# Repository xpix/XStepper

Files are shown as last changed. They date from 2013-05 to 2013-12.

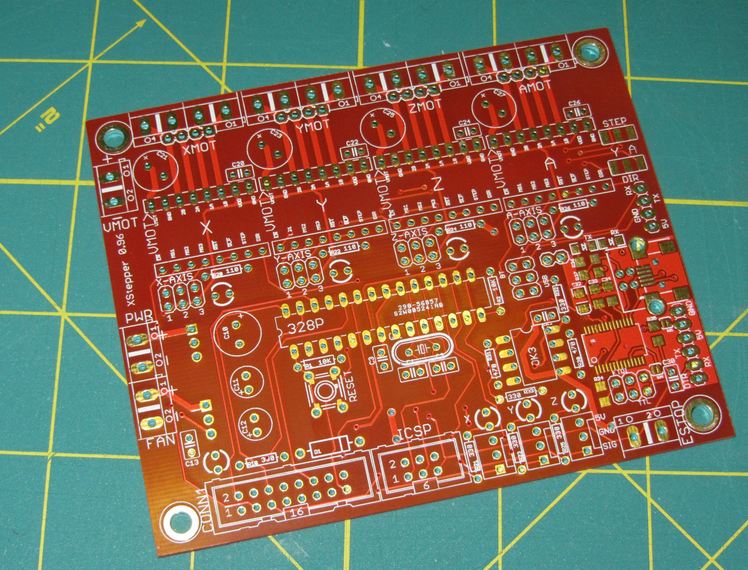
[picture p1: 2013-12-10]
Docs/board_096.JPG

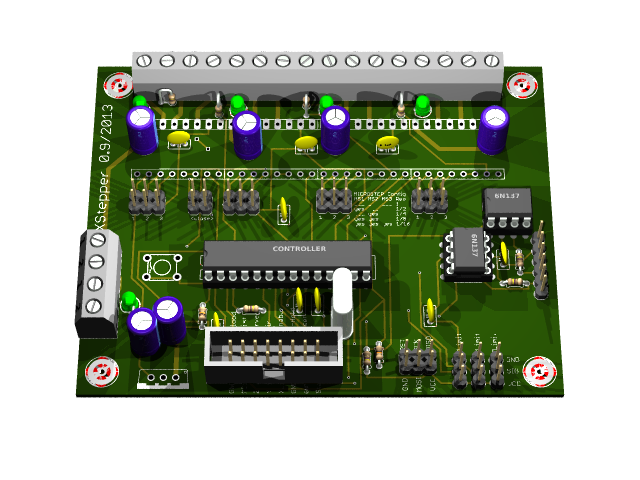
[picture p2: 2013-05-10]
eagle3d/XStepper.bmp

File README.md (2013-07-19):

XStepper
=============

A new Solution with Grbl Firmware to use cnc mills or 3d printers.

created by Frank Herrmann (xpix), Godsplan

---------------

The XStepper includes the following features:

- ATMega328u (DIL Package)
- USB Connection using USB-FTDI
- Opto-Couplers for USB Connection
- ICSP-Connector for flashing the firmware
- GRBL Firmware (v0.8) and GRBL Pinout
- Connector for External Buttons for spindle, reset, etc...
- Support for four Pololu A4988 or Pololu DRV8825 Modules
- Supports dual-Y motion
- Supports cooling fan
- Supports XYZ-Limit in extra pinheader
- LED's for every axis
- LED's for every Limit
- Power LED
- AK500 Screw terminal for Steppers
- Connector for Bluetooth TTL Modules

---------------
v0.9.1

- add optional pullup resistors (1k/5V) for Hallo Sesnor switches (Cherry MP101401)
   http://www.cherrycorp.com/english/sensors/pdf/MP1014_Series.pdf

v0.9 

- created schema files
- created .brd

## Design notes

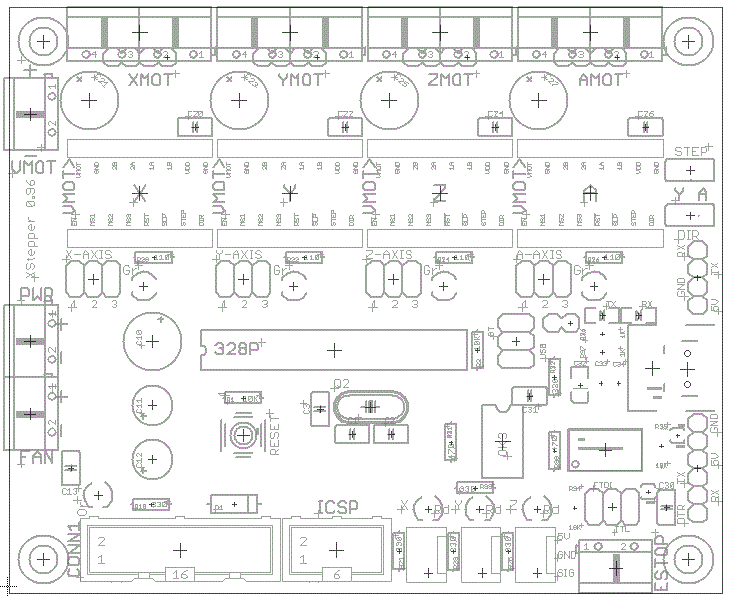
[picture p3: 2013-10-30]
Docs/board_top.gif

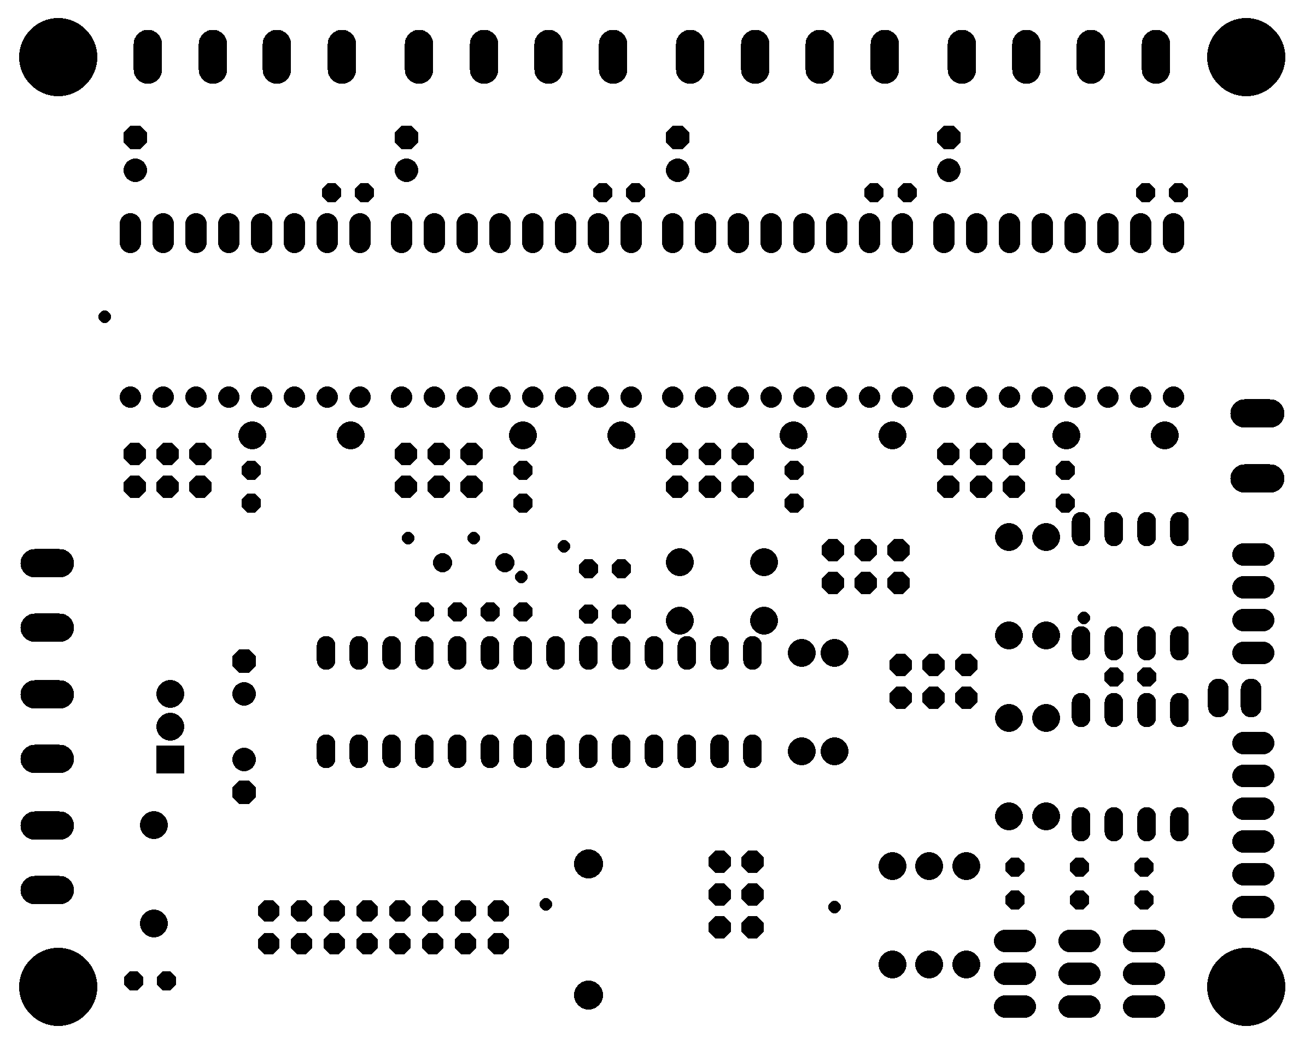
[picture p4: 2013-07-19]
eagleUp/eagleUp_XStepper_bottom_mask.png

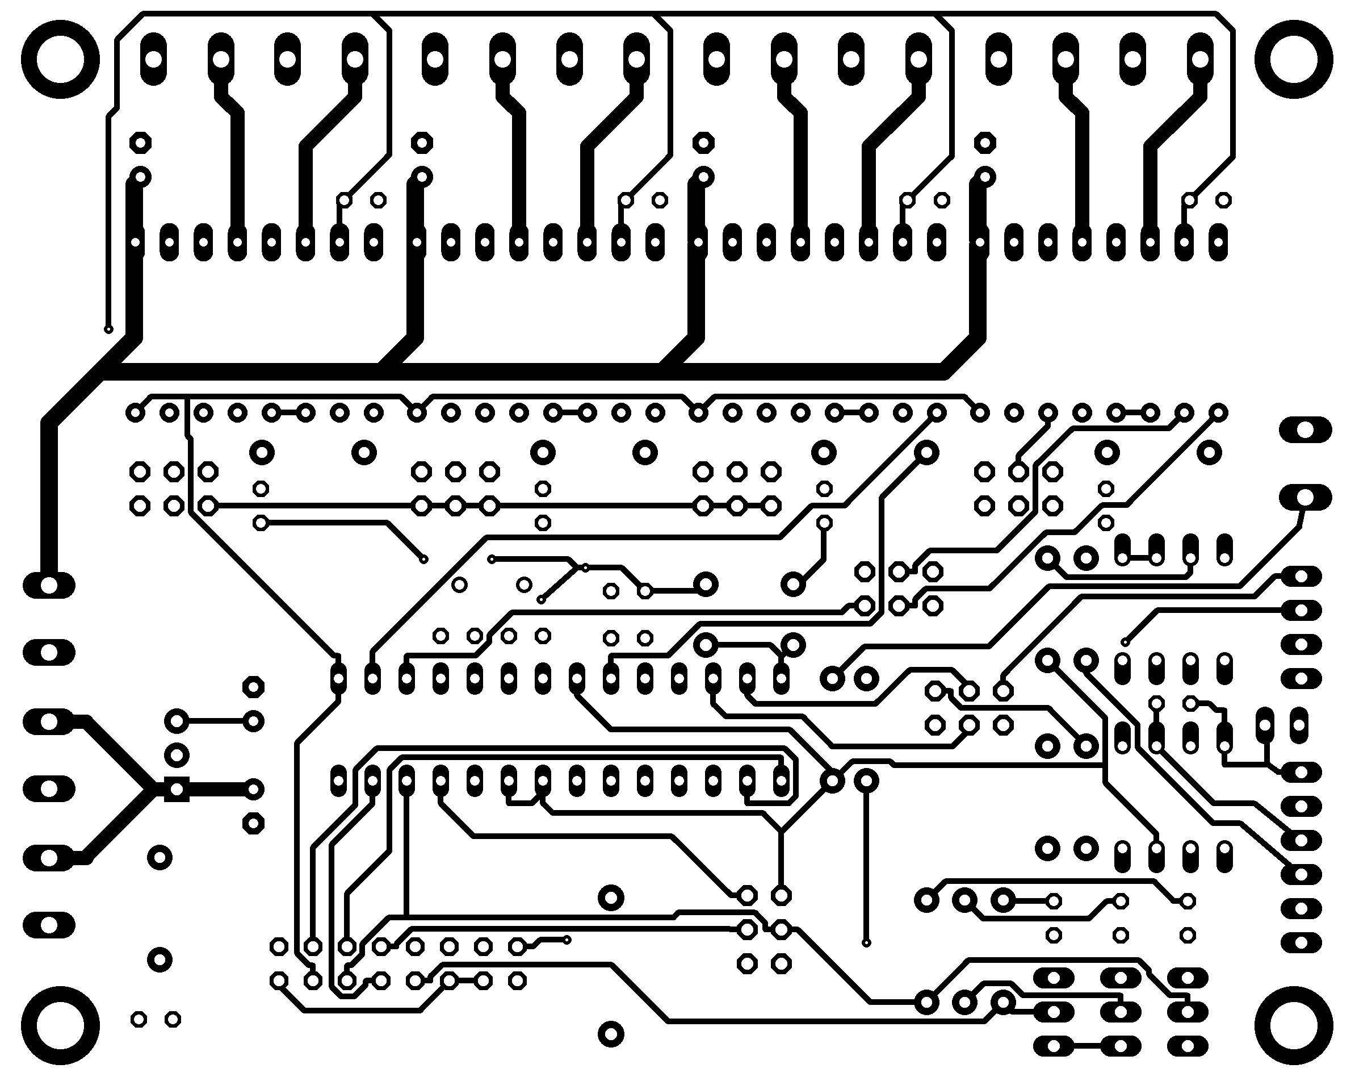
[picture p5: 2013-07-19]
eagleUp/eagleUp_XStepper_top.png

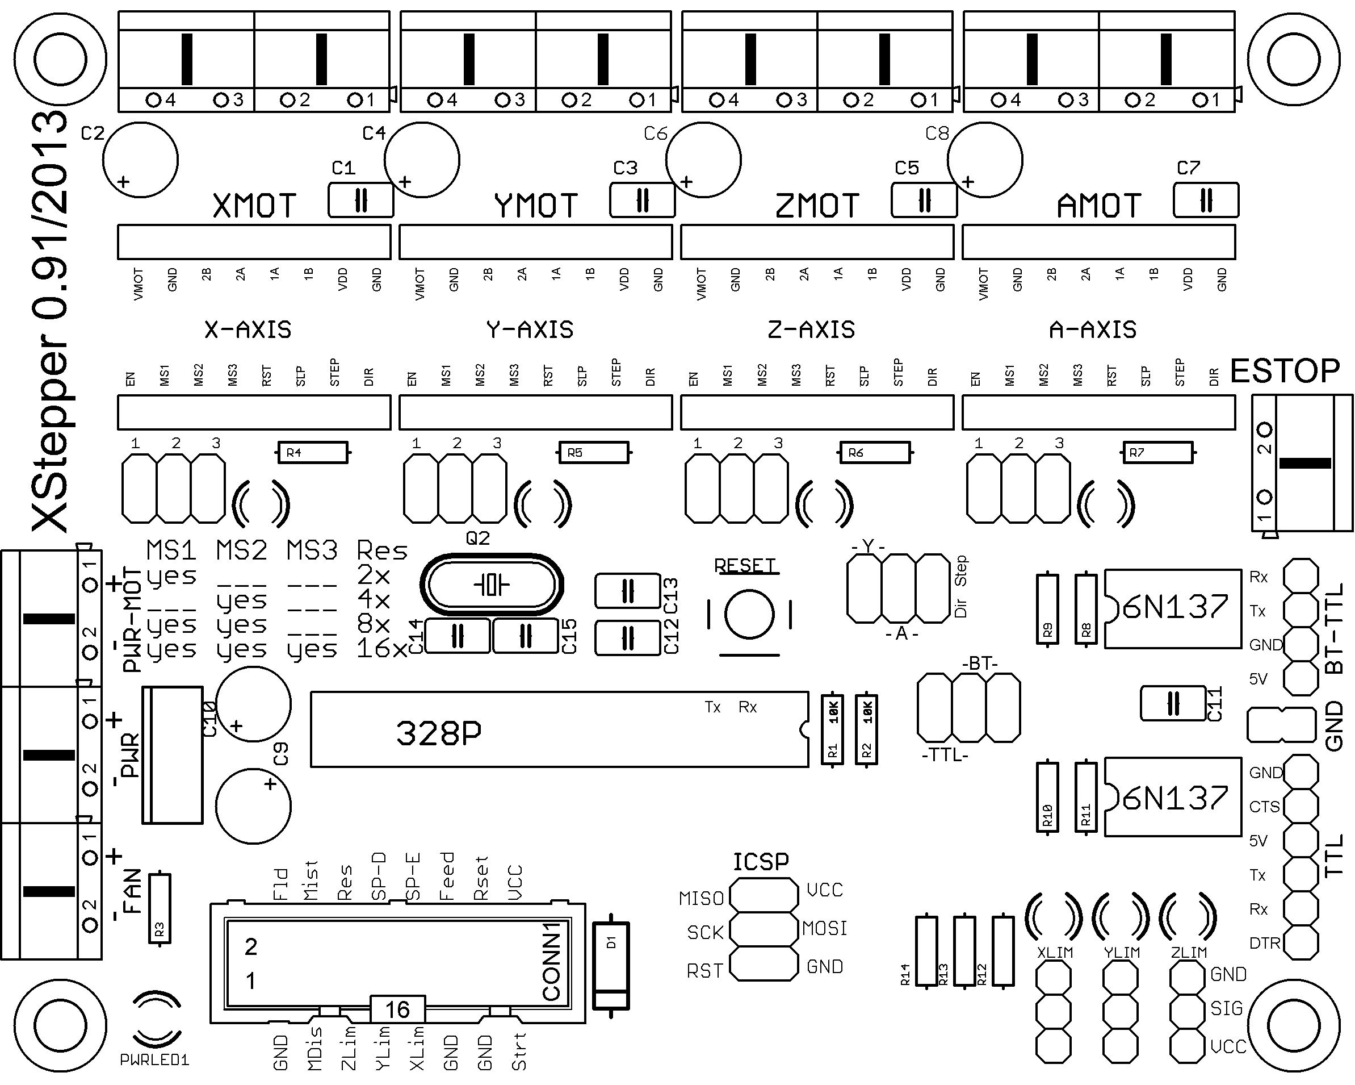
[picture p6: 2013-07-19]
eagleUp/eagleUp_XStepper_top_silk.png

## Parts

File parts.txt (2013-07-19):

Partlist

Exported from XStepper.sch at 11.07.2013 17:57:24

EAGLE Version 6.3.0 Copyright (c) 1988-2012 CadSoft

Assembly variant: 

Part           Value              Device             Package            Library        Sheet

328P           CONTROLLER         MEGA8-P            DIL28-3            Bibsatmel      1
A-AXIS                            PINHD-2X3          2X03               pinhead        1
ALED                              LED3MM             LED3MM             led            1
AMOT                              AK500/4            AK500/4            con-ptr500     1
BT-TTL                            PINHD-1X4          1X04               pinhead        1
C1             0.1uF              C-EU025-025X050    C025-025X050       resistor       1
C2             47uF               CPOL-USE2.5-6      E2,5-6             resistor       1
C3             0.1uF              C-EU025-025X050    C025-025X050       resistor       1
C4             0.1uF              C-EU025-025X050    C025-025X050       resistor       1
C5             47uF               CPOL-USE2.5-6      E2,5-6             resistor       1
C6             0.1uF              C-EU025-025X050    C025-025X050       resistor       1
C7             47uF               CPOL-USE2.5-6      E2,5-6             resistor       1
C8             47uF               CPOL-USE2.5-6      E2,5-6             resistor       1
C9             47uF               CPOL-USE2.5-6      E2,5-6             resistor       1
C10            47uF               CPOL-USE2.5-6      E2,5-6             resistor       1
C11            18pF               C-EU025-025X050    C025-025X050       resistor       1
C12            18pF               C-EU025-025X050    C025-025X050       resistor       1
C13            0.1uF              C-EU025-025X050    C025-025X050       resistor       1
C14            0.1uF              C-EU025-025X050    C025-025X050       resistor       1
C15            0.1uF              C-EU025-025X050    C025-025X050       resistor       1
CONN1                             ML16               ML16               con-ml         1
DUALY                             PINHD-2X2          2X02               pinhead        1
FAN                               AK500/2            AK500/2            con-ptr500     1
H5             MOUNT-PAD-ROUND3.6 MOUNT-PAD-ROUND3.6 3,6-PAD            holes          1
H6             MOUNT-PAD-ROUND3.6 MOUNT-PAD-ROUND3.6 3,6-PAD            holes          1
H7             MOUNT-PAD-ROUND3.6 MOUNT-PAD-ROUND3.6 3,6-PAD            holes          1
H8             MOUNT-PAD-ROUND3.6 MOUNT-PAD-ROUND3.6 3,6-PAD            holes          1
IC1             LM7805            V_REG_78XX         78XXL-CUSTOM       SparkFun       1
ICSP                              PINHD-2X3          2X03               pinhead        1
OK1            6N137              6N137              DIL08              optocoupler    1
OK2            6N137              6N137              DIL08              optocoupler    1
PWR                               AK500/2            AK500/2            con-ptr500     1
PWRLED1                           LED3MM             LED3MM             led            1
Q2             16 MHZ             CRYSTALHC49S       HC49/S             crystal        1
R1             10k                R-EU_0204/5        0204/5             resistor       1
R2             470                R-EU_0204/5        0204/5             resistor       1
R3             470                R-EU_0204/5        0204/5             resistor       1
R4             470                R-EU_0204/5        0204/5             resistor       1
R5             470                R-EU_0204/2V       0204V              resistor       1
R6             10k                R-EU_0204/5        0204/5             resistor       1
R7             470                R-EU_0204/5        0204/5             resistor       1
R8             470                R-EU_0204/2V       0204V              resistor       1
R9             470                R-EU_0204/2V       0204V              resistor       1
R10            470                R-EU_0204/2V       0204V              resistor       1
R11            470                R-EU_0204/2V       0204V              resistor       1
R12            470                R-EU_0204/2V       0204V              resistor       1
R13            1k                 R-EU_0204/2V       0204V              resistor       1
R14            470                R-EU_0204/2V       0204V              resistor       1
R15            1k                 R-EU_0204/2V       0204V              resistor       1
R16            1k                 R-EU_0204/2V       0204V              resistor       1
R17            1k                 R-EU_0204/2V       0204V              resistor       1
RESET          RESET              TAC_SWITCHPTH      TACTILE-PTH        SparkFun       1
STEPPERDRIVER  POLOLU-A4988       POLOLU-ALLEGRO     POLOLU-ALLEGRO-PTH pololu-allegro 1
STEPPERDRIVER1 POLOLU-A4988       POLOLU-ALLEGRO     POLOLU-ALLEGRO-PTH pololu-allegro 1
STEPPERDRIVER2 POLOLU-A4988       POLOLU-ALLEGRO     POLOLU-ALLEGRO-PTH pololu-allegro 1
STEPPERDRIVER3 POLOLU-A4988       POLOLU-ALLEGRO     POLOLU-ALLEGRO-PTH pololu-allegro 1
TTL            GND                PINHD-1X6          1X06               pinhead        1
X-AXIS                            PINHD-2X3          2X03               pinhead        1
XLED                              LED3MM             LED3MM             led            1
XLIMIT                            PINHD-1X3          1X03               pinhead        1
XMOT                              AK500/4            AK500/4            con-ptr500     1
XSTLED                            LED3MM             LED3MM             led            1
Y-AXIS                            PINHD-2X3          2X03               pinhead        1
YLED                              LED3MM             LED3MM             led            1
YLIMIT                            PINHD-1X3          1X03               pinhead        1
YMOT                              AK500/4            AK500/4            con-ptr500     1
YSTLED                            LED3MM             LED3MM             led            1
Z-AXIS                            PINHD-2X3          2X03               pinhead        1
ZLED                              LED3MM             LED3MM             led            1
ZLIMIT                            PINHD-1X3          1X03               pinhead        1
ZMOT                              AK500/4            AK500/4            con-ptr500     1
ZSTLED                            LED3MM             LED3MM             led            1

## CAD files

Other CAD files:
eagleUp/XStepper.skp

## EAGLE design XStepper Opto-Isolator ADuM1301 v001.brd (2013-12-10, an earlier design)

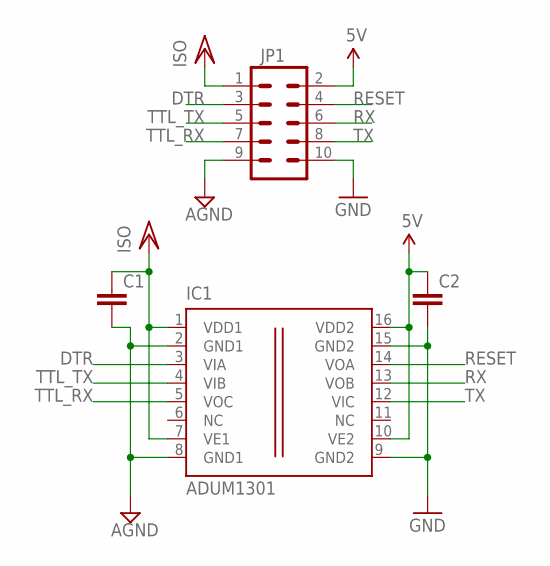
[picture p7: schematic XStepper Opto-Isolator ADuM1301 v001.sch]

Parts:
C1, C2: CAP0805; 0805
IC1: ADUM1301; SO-16W
JP1: M05X2PTH; AVR_ICSP

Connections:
5V: C2.1, IC1.10 (VE2), IC1.16 (VDD2), JP1.2
AGND: C1.2, IC1.2 (GND1), IC1.8 (GND1), JP1.9
DTR: IC1.3 (VIA), JP1.3
GND: C2.2, IC1.9 (GND2), IC1.15 (GND2), JP1.10
RESET: IC1.14 (VOA), JP1.4
RX: IC1.13 (VOB), JP1.6
TTL_RX: IC1.5 (VOC), JP1.7
TTL_TX: IC1.4 (VIB), JP1.5
TX: IC1.12 (VIC), JP1.8
VCC/2: C1.1, IC1.1 (VDD1), IC1.7 (VE1), JP1.1

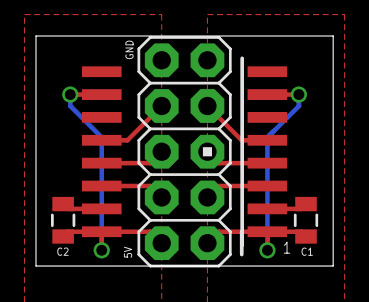
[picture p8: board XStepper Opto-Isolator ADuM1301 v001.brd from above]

Board: 2 copper layers, 16.5 x 12.8 mm, 4 parts (0 on the bottom side), 10 nets.

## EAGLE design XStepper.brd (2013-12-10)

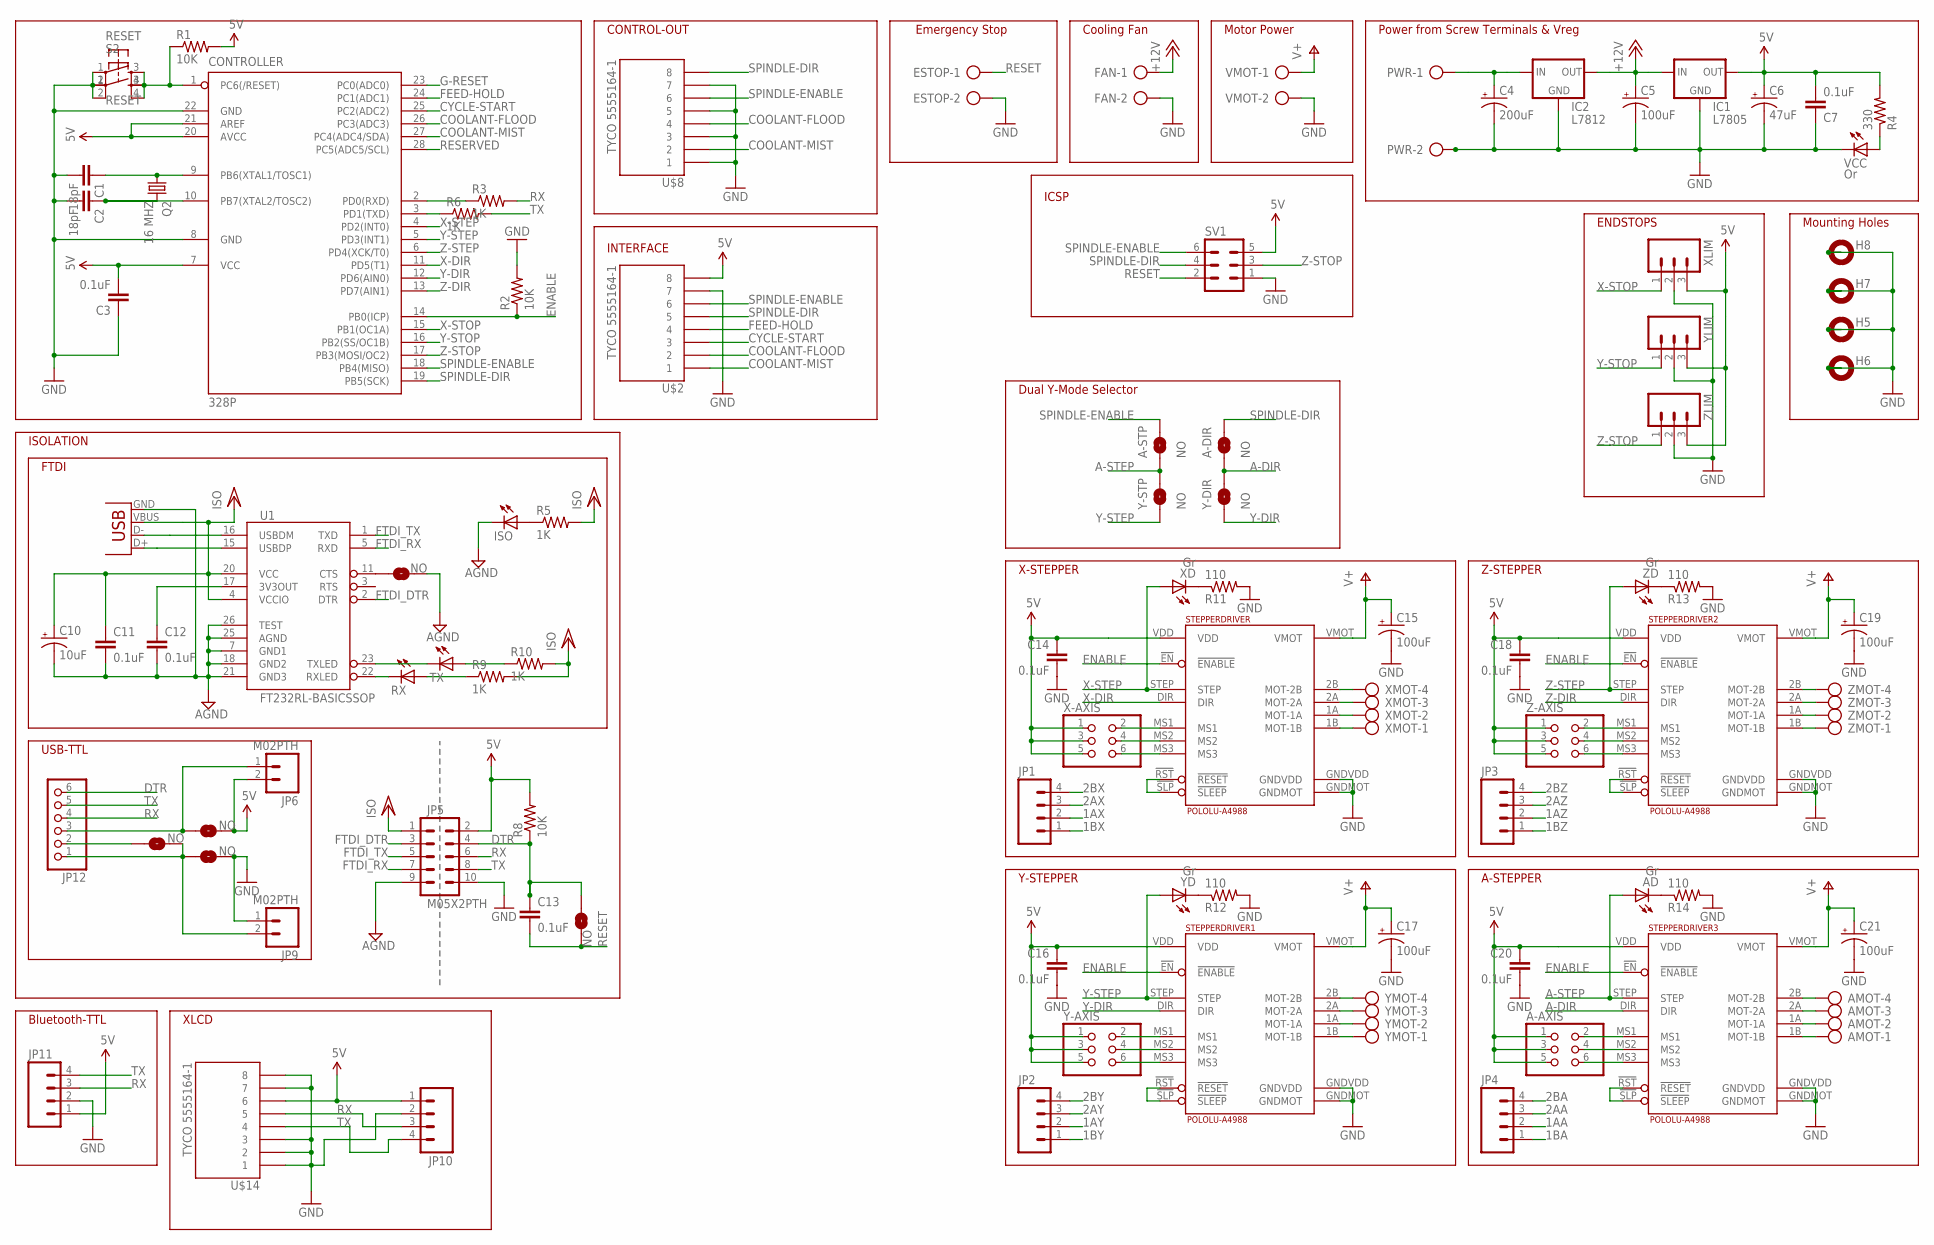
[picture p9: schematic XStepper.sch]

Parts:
5V: NO; SJ_2S-NO
328P: CONTROLLER; DIL28-3
A-AXIS: PINHD-2X3; 2X03
A-DIR: NO; SJ_2S-NO
A-STP: NO; SJ_2S-NO
AD: Gr; LED3MM
AMOT: AK500/4
C1, C2: 18pF; C025-025X050
C3, C7, C13, C14, C16, C18, C20: 0.1uF; C025-025X050
C4: 200uF; E3,5-8
C5: 100uF; E2,5-6
C6: 47uF; E2,5-6
C10: 10uF; EIA3216
C11, C12: 0.1uF; 1206
C15, C17, C19, C21: 100uF; E3,5-8
CTS: NO; SJ_2S-NO
CTS-FTDI: NO; SJ_2S-NO
DTR: NO; SJ_2S-NO
ESTOP: AK500/2
FAN: AK500/2
GND: NO; SJ_2S-NO
H5, H6, H7, H8: MOUNT-PAD-ROUND3.6; 3,6-PAD
IC1: L7805; TO220-IGO
IC2: L7812; TO220-IGO
ISO: LED3MM
JP1, JP2, JP3, JP4, JP10, JP11: M04PTH; 1X04
JP5: M05X2PTH; AVR_ICSP
JP6, JP9: M02PTH; 1X02
JP7: USBSMD; USB-MINIB
JP12: PINHD-1X6; 1X06
PWR: AK500/2
Q2: 16 MHZ; HC49/S
R1, R2, R8: 10K; AXIAL-0.3
R3, R6: 1K; AXIAL-0.3
R4: 330; AXIAL-0.3
R5, R9, R10: 1K; 1206
R11, R12, R13, R14: 110; AXIAL-0.3
RESET: RESET; TACTILE-PTH
RX: LED3MM
S2: TAC_SWITCHSMD; TACTILE_SWITCH_SMD
STEPPERDRIVER, STEPPERDRIVER1, STEPPERDRIVER2, STEPPERDRIVER3: POLOLU-A4988; POLOLU-ALLEGRO-PTH
SV1: ML6
TX: LED3MM
U1: FT232RL-BASICSSOP; SSOP28DB
U$2, U$8, U$14: TYCO 5555164-1; RJ45-8
VCC: Or; LED3MM
VMOT: AK500/2
X-AXIS: PINHD-2X3; 2X03
XD: Gr; LED3MM
XLIM: M03POLAR; MOLEX-1X3
XMOT: AK500/4
Y-AXIS: PINHD-2X3; 2X03
Y-DIR: NO; SJ_2S-NO
Y-STP: NO; SJ_2S-NO
YD: Gr; LED3MM
YLIM: M03POLAR; MOLEX-1X3
YMOT: AK500/4
Z-AXIS: PINHD-2X3; 2X03
ZD: Gr; LED3MM
ZLIM: M03POLAR; MOLEX-1X3
ZMOT: AK500/4

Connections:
1AA: AMOT.2, JP4.2, STEPPERDRIVER3.1A (MOT-1A)
1AX: JP1.2, STEPPERDRIVER.1A (MOT-1A), XMOT.2
1AY: JP2.2, STEPPERDRIVER1.1A (MOT-1A), YMOT.2
1AZ: JP3.2, STEPPERDRIVER2.1A (MOT-1A), ZMOT.2
1BA: AMOT.1, JP4.1, STEPPERDRIVER3.1B (MOT-1B)
1BX: JP1.1, STEPPERDRIVER.1B (MOT-1B), XMOT.1
1BY: JP2.1, STEPPERDRIVER1.1B (MOT-1B), YMOT.1
1BZ: JP3.1, STEPPERDRIVER2.1B (MOT-1B), ZMOT.1
2AA: AMOT.3, JP4.3, STEPPERDRIVER3.2A (MOT-2A)
2AX: JP1.3, STEPPERDRIVER.2A (MOT-2A), XMOT.3
2AY: JP2.3, STEPPERDRIVER1.2A (MOT-2A), YMOT.3
2AZ: JP3.3, STEPPERDRIVER2.2A (MOT-2A), ZMOT.3
2BA: AMOT.4, JP4.4, STEPPERDRIVER3.2B (MOT-2B)
2BX: JP1.4, STEPPERDRIVER.2B (MOT-2B), XMOT.4
2BY: JP2.4, STEPPERDRIVER1.2B (MOT-2B), YMOT.4
2BZ: JP3.4, STEPPERDRIVER2.2B (MOT-2B), ZMOT.4
5V: 5V.2, 328P.7 (VCC), 328P.20 (AVCC), 328P.21 (AREF), A-AXIS.1, A-AXIS.3, A-AXIS.5, C3.2, C6.+, C7.2, C14.1, C16.1, C18.1, C20.1, IC1.OUT, JP5.2, JP6.2, JP10.1, JP11.1, R1.P$2 (2), R4.P$2 (2), R8.P$2 (2), STEPPERDRIVER.VDD, STEPPERDRIVER1.VDD, STEPPERDRIVER2.VDD, STEPPERDRIVER3.VDD, SV1.5, U$2.8, U$14.6, X-AXIS.1, X-AXIS.3, X-AXIS.5, XLIM.3, Y-AXIS.1, Y-AXIS.3, Y-AXIS.5, YLIM.3, Z-AXIS.1, Z-AXIS.3, Z-AXIS.5, ZLIM.3
+12V: C5.+, FAN.1, IC1.IN, IC2.OUT
A-DIR: A-DIR.1, STEPPERDRIVER3.DIR, Y-DIR.2
A-STEP: A-STP.1, AD.A, STEPPERDRIVER3.STEP, Y-STP.2
AGND: C10.C (-), C11.2, C12.2, CTS-FTDI.2, ISO.K (C), JP5.9, JP7.GND, U1.7 (GND1), U1.18 (GND2), U1.21 (GND3), U1.25 (AGND), U1.26 (TEST)
COOLANT-FLOOD: 328P.26 (PC3(ADC3)), U$2.2, U$8.4
COOLANT-MIST: 328P.27 (PC4(ADC4/SDA)), U$2.1, U$8.2
CYCLE-START: 328P.25 (PC2(ADC2)), U$2.3
DTR: C13.1, DTR.1, JP5.4, JP12.6, R8.P$1 (1)
ENABLE: 328P.14 (PB0(ICP)), R2.P$1 (1), STEPPERDRIVER.!EN (!ENABLE), STEPPERDRIVER1.!EN (!ENABLE), STEPPERDRIVER2.!EN (!ENABLE), STEPPERDRIVER3.!EN (!ENABLE)
FEED-HOLD: 328P.24 (PC1(ADC1)), U$2.4
FTDI_DTR: JP5.3, U1.2 (DTR)
FTDI_RX: JP5.7, U1.5 (RXD)
FTDI_TX: JP5.5, U1.1 (TXD)
G-RESET: 328P.23 (PC0(ADC0))
GND: 328P.8 (GND), 328P.22 (GND), C1.2, C2.2, C3.1, C4.-, C5.-, C6.-, C7.1, C14.2, C15.-, C16.2, C17.-, C18.2, C19.-, C20.2, C21.-, ESTOP.2, FAN.2, GND.2, H5.B3,6, H6.B3,6, H7.B3,6, H8.B3,6, IC1.GND, IC2.GND, JP5.10, JP9.1, JP10.2, JP11.2, PWR.2, R2.P$2 (2), R11.P$2 (2), R12.P$2 (2), R13.P$2 (2), R14.P$2 (2), RESET.1, RESET.2, S2.1, S2.2, STEPPERDRIVER.GNDMOT, STEPPERDRIVER.GNDVDD, STEPPERDRIVER1.GNDMOT, STEPPERDRIVER1.GNDVDD, STEPPERDRIVER2.GNDMOT, STEPPERDRIVER2.GNDVDD, STEPPERDRIVER3.GNDMOT, STEPPERDRIVER3.GNDVDD, SV1.1, U$2.7, U$8.1, U$8.3, U$8.5, U$8.7, U$14.1, U$14.2, U$14.3, U$14.7, U$14.8, VCC.K (C), VMOT.2, XLIM.2, YLIM.2, ZLIM.2
unnamed: C12.1, U1.17 (3V3OUT)
unnamed: JP7.D+, U1.15 (USBDP)
unnamed: JP7.D-, U1.16 (USBDM)
unnamed: ISO.A, R5.1
unnamed: STEPPERDRIVER.!RST (!RESET), STEPPERDRIVER.!SLP (!SLEEP)
unnamed: STEPPERDRIVER.MS1, X-AXIS.2
unnamed: STEPPERDRIVER.MS2, X-AXIS.4
unnamed: STEPPERDRIVER.MS3, X-AXIS.6
unnamed: 328P.2 (PD0(RXD)), R3.P$1 (1)
unnamed: CTS.1, JP12.2
unnamed: TX.K (C), U1.23 (TXLED)
unnamed: RX.K (C), U1.22 (RXLED)
unnamed: STEPPERDRIVER1.!RST (!RESET), STEPPERDRIVER1.!SLP (!SLEEP)
unnamed: STEPPERDRIVER1.MS1, Y-AXIS.2
unnamed: STEPPERDRIVER1.MS2, Y-AXIS.4
unnamed: STEPPERDRIVER1.MS3, Y-AXIS.6
unnamed: R9.1, RX.A
unnamed: R10.1, TX.A
unnamed: CTS-FTDI.1, U1.11 (CTS)
unnamed: R11.P$1 (1), XD.K (C)
unnamed: STEPPERDRIVER2.!RST (!RESET), STEPPERDRIVER2.!SLP (!SLEEP)
unnamed: STEPPERDRIVER2.MS1, Z-AXIS.2
unnamed: STEPPERDRIVER2.MS2, Z-AXIS.4
unnamed: STEPPERDRIVER2.MS3, Z-AXIS.6
unnamed: R12.P$1 (1), YD.K (C)
unnamed: R13.P$1 (1), ZD.K (C)
unnamed: AD.K (C), R14.P$1 (1)
unnamed: STEPPERDRIVER3.!RST (!RESET), STEPPERDRIVER3.!SLP (!SLEEP)
unnamed: A-AXIS.2, STEPPERDRIVER3.MS1
unnamed: A-AXIS.4, STEPPERDRIVER3.MS2
unnamed: A-AXIS.6, STEPPERDRIVER3.MS3
unnamed: 328P.9 (PB6(XTAL1/TOSC1)), C1.1, Q2.1
unnamed: 328P.10 (PB7(XTAL2/TOSC2)), C2.1, Q2.2
unnamed: 328P.3 (PD1(TXD)), R6.P$1 (1)
unnamed: 5V.1, JP6.1, JP12.3
unnamed: R4.P$1 (1), VCC.A
unnamed: CTS.2, GND.1, JP9.2, JP12.1
RESERVED: 328P.28 (PC5(ADC5/SCL))
RESET: 328P.1 (PC6(/RESET)), C13.2, DTR.2, ESTOP.1, R1.P$1 (1), RESET.3, RESET.4, S2.3, S2.4, SV1.2
RX: JP5.6, JP10.3, JP11.3, JP12.4, R3.P$2 (2), U$14.5
SPINDLE-DIR: 328P.19 (PB5(SCK)), A-DIR.2, SV1.4, U$2.5, U$8.8
SPINDLE-ENABLE: 328P.18 (PB4(MISO)), A-STP.2, SV1.6, U$2.6, U$8.6
TX: JP5.8, JP10.4, JP11.4, JP12.5, R6.P$2 (2), U$14.4
V+: C15.+, C17.+, C19.+, C21.+, STEPPERDRIVER.VMOT, STEPPERDRIVER1.VMOT, STEPPERDRIVER2.VMOT, STEPPERDRIVER3.VMOT, VMOT.1
VCC/2: C10.A (+), C11.1, JP5.1, JP7.VBUS, R5.2, R9.2, R10.2, U1.4 (VCCIO), U1.20 (VCC)
VIN: C4.+, IC2.IN, PWR.1
X-DIR: 328P.11 (PD5(T1)), STEPPERDRIVER.DIR
X-STEP: 328P.4 (PD2(INT0)), STEPPERDRIVER.STEP, XD.A
X-STOP: 328P.15 (PB1(OC1A)), XLIM.1
Y-DIR: 328P.12 (PD6(AIN0)), STEPPERDRIVER1.DIR, Y-DIR.1
Y-STEP: 328P.5 (PD3(INT1)), STEPPERDRIVER1.STEP, Y-STP.1, YD.A
Y-STOP: 328P.16 (PB2(SS/OC1B)), YLIM.1
Z-DIR: 328P.13 (PD7(AIN1)), STEPPERDRIVER2.DIR
Z-STEP: 328P.6 (PD4(XCK/T0)), STEPPERDRIVER2.STEP, ZD.A
Z-STOP: 328P.17 (PB3(MOSI/OC2)), SV1.3, ZLIM.1

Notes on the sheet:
X-STEPPER
Y-STEPPER
Z-STEPPER
Power from Screw Terminals & Vreg
A-STEPPER
Dual Y-Mode Selector
ISOLATION
Cooling Fan
Mounting Holes
USB-TTL
INTERFACE
Bluetooth-TTL
Emergency Stop
ENDSTOPS
FTDI
Motor Power
CONTROL-OUT
ICSP
XLCD

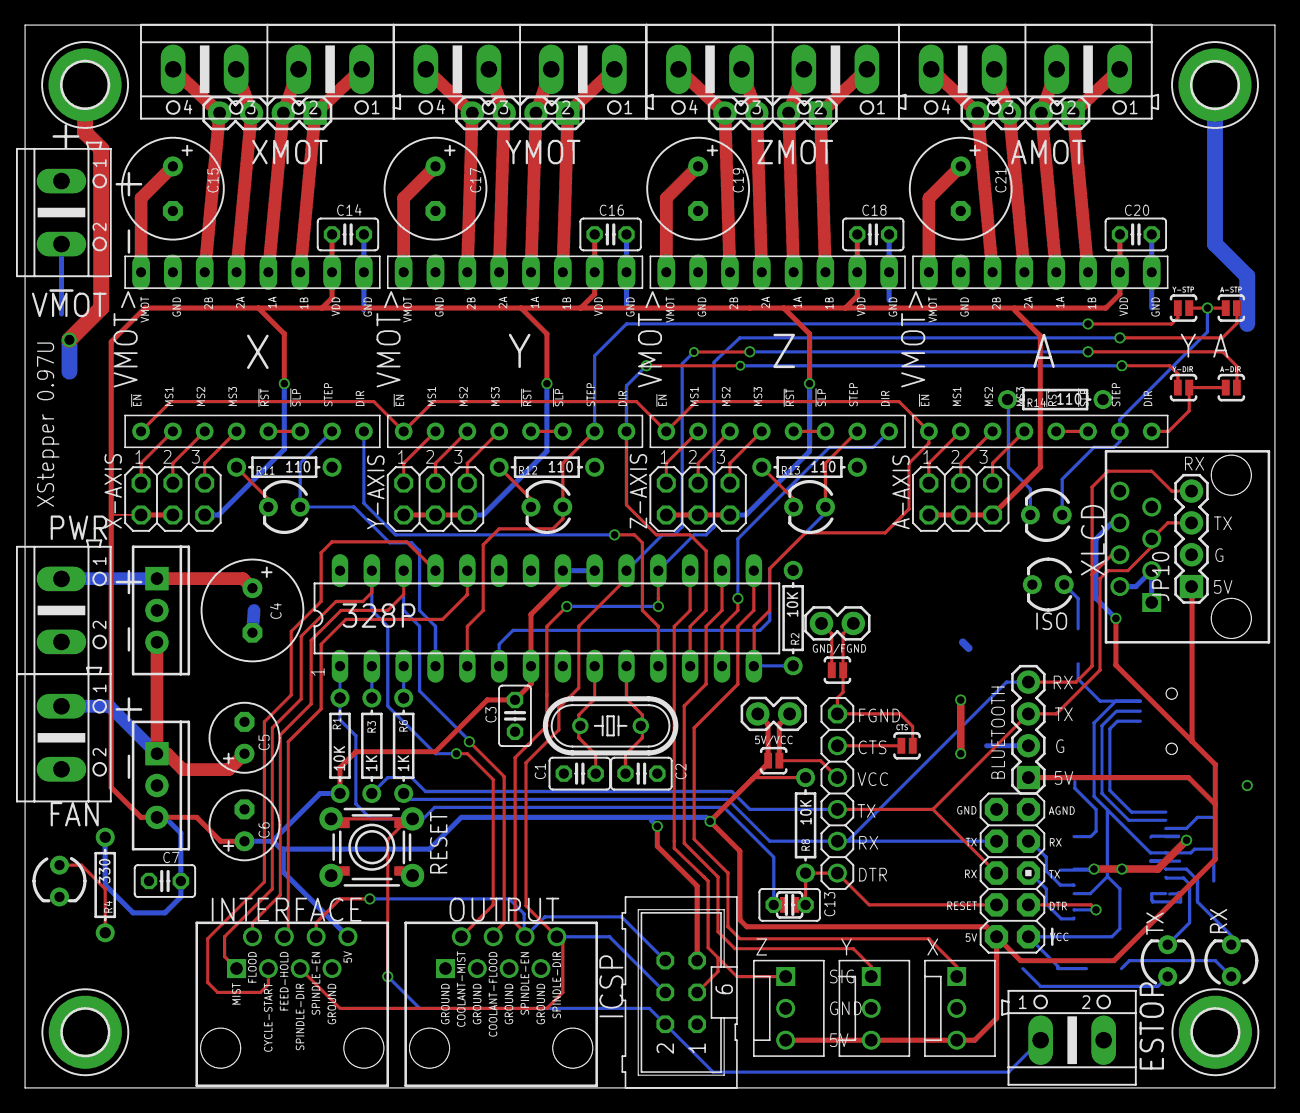
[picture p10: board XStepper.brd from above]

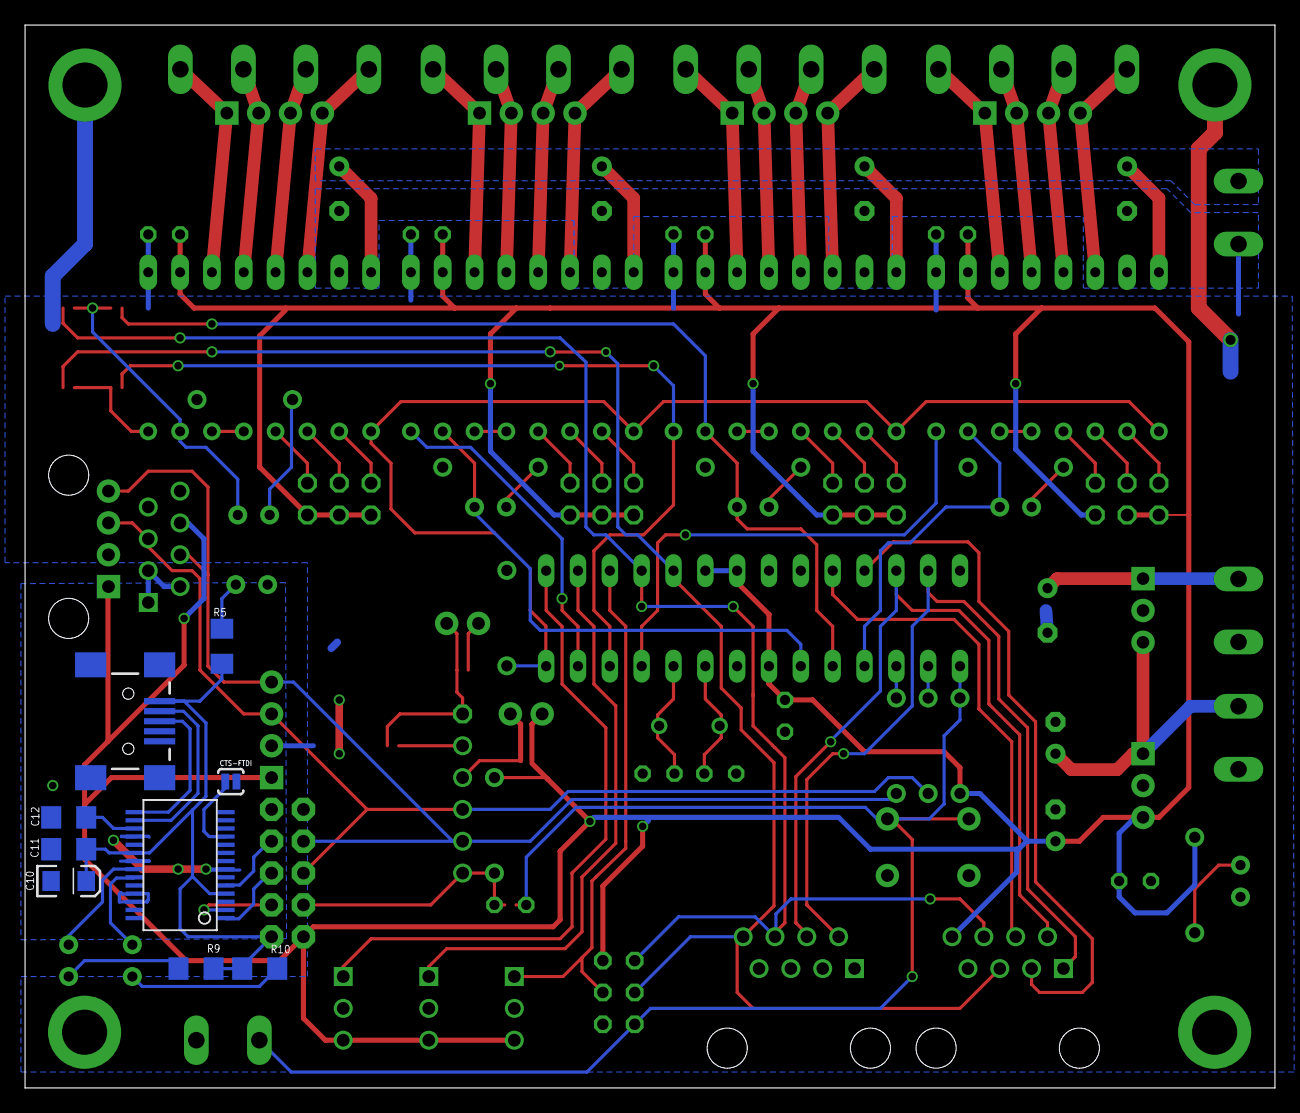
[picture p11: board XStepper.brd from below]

Board: 2 copper layers, 99.7 x 84.8 mm, 94 parts (9 on the bottom side), 85 nets.

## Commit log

2013-05-10 initial fork from GRBLMainboard
    [XStepper.GBL, XStepper.GBO, XStepper.GBP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]
2013-05-21 add Bluetooth Connector
    Add connector for Bluetooth TTL Module.
    [XStepper.skp]
2013-05-24 Remove unused files
    - also add comment to Readme.
    [XStepper.GBL, XStepper.GBO, XStepper.GBP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]
2013-05-24 refresh sketchup file
    [XStepper.skp]
2013-06-03 add pullup resistors for Hallo Sensor switches (Cherry MP101401)
    [XStepper.brd, XStepper.sch]
2013-07-19 Bugfree version from 0.9 to produce in ITEAD
    Version 0.91 from Matt to produce without bugs
    [XStepper.GBL, XStepper.GBO, XStepper.GBP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]
2013-07-30 - change header ICSP
    - more space between caps at 7805
    - add VCC area on top to save wires
    [XStepper.brd, XStepper.sch]
2013-08-01 - Bugfix COMSERIAL
    change pins on comserial block
    remove some unused files
    [XStepper.brd, XStepper.sch]
2013-08-09 - bugfix diode
    - add new autorouting
    - move emergency screw near to cpu
    [XStepper.brd, XStepper.sch]
2013-08-14 - add VMOT sign to driver for users
    - remove circle for pod cuz they are different on drivers
    [XStepper.brd, XStepper.sch]
2013-08-19 - some changes for community
    * move screw terminals for motors 1mm up for bigger caps
    * add a 12V voltage regulator for fan
    * replace powerled resitor to a small one
    [XStepper.brd, XStepper.sch]
2013-08-20 - bigger vmot caps 8mm
    [XStepper.brd, XStepper.sch]
2013-08-22 - add 7812 regulator for fan and main 5V voltage regulator
    - change c10 to small cap cuz he get only 12v with new regulator
    [XStepper.brd, XStepper.sch]
2013-09-19 - last design from matt
    - correct some issues
    - run all eagle tests
    [XStepper.brd, XStepper.sch]
2013-09-19 - remove old gerber files
    [XStepper.GBL, XStepper.GBO, XStepper.GBP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]
2013-10-09 - some changes from matt and produce in fab 0.95
    [XStepper.brd, XStepper.sch]
2013-10-30 - gerber files for ITEAD 0.96
    - new pic for docs
    [XStepper.brd, XStepper.sch]
2013-12-10 - version 0.97 to fab
    *On-board USB in now in the bottom of the board
    *USB isolation header moved.
    *Bluetooth header moved
    *Bluetooth dip/jumpers removed - bluetooth is always-on
    *FTDI header moved
    *FTDI now can be tied to 5V and GND for isolation or to forego isolation
    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
    [XStepper Opto-Isolator ADuM1301 v001.brd, XStepper Opto-Isolator ADuM1301 v001.sch, XStepper Opto-Isolator ADuM1301 v002.brd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]

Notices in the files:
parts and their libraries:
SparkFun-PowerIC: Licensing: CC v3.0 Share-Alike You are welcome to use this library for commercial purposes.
